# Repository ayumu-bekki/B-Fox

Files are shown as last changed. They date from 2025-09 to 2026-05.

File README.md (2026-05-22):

[English documentation is available here](./README.en.md)

# B-Fox
B-Fox logo

# B-Fox App Store (iOS)
B-Fox Receiver for iOS (https://apps.apple.com/jp/app/b-fox-receiver/id6759365457)

https://apps.apple.com/jp/app/b-fox-receiver/id6759365457

# B-Fox Beacon Control Panel
https://ayumu-bekki.github.io/B-Fox/bfox_beacon/web_client/

## 概要
B-Fox は、Bluetooth Low Energy (BLE) を利用し、Foxハンティングの遊びを再現・実現するためのオープンソースプロジェクトです。
導入・参加の障壁を下げ、「電波の強弱で隠し場所を探す」という無線方向探索のコアな楽しさを手軽に実現することを目指しています。

このプロジェクトを始めるにあたり、既存のFoxハンティング・ARDFに以下のような課題があり手軽でないと感じていました。
- 送信機・受信機のコストが高い
- 運用(ビーコン設置)に免許が必要
- アマチュア無線の帯域を利用するため、商用利用が不可 
- ARDFは競技のため厳格なルールがある

そこで、誰でも免許なしに利用できるBLEを利用して手軽に遊べる無線方向探索の遊びを実現します。

## 運用について
基本遊びだが発展としてARDF競技があるという位置付けを想定し、パークARDFを参考にルールを緩くする方向で運用資料(草案)を作成しました。
[B-Fox 運用・ルール案](./operation/OPERATION.md)

## 送信機・受信機について
[送受信機デバイスドキュメント](./docs/README.md) を参考にしてください。
このプロジェクトには、プログラム一式と、PCB・3Dプリンタで出力できるデータが含まれています。

プロトコルにiBeacon (BLE)を利用しているため、LightBlue (https://punchthrough.com/lightblue/) などをインストールすれば遊ぶことができます。

また、iOS向けに専用受信アプリを用意しています。
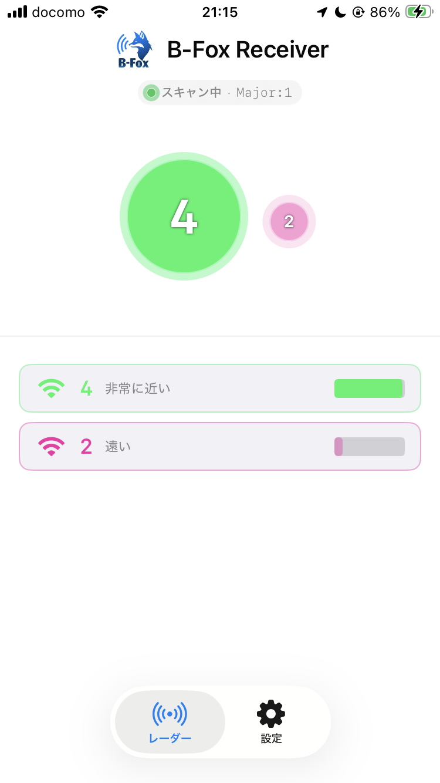
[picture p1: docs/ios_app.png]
B-Fox Receiver for iOS


### QRコードによるビーコン設定
iOS受信アプリでは、QRコードを読み取ってビーコンターゲット（UUID + MajorID）を設定できます。

**QRコードフォーマット:**
```
BFOX:<UUID>:<MajorID>
```

| 要素 | 説明 | 制約 |
|---|---|---|
| `BFOX` | 固定プレフィックス（大文字小文字不問） | 必須 |
| `UUID` | iBeaconのUUID | 標準的なUUID形式 |
| `MajorID` | iBeaconのMajor ID | 整数 0〜65535 |

**例:**
```
BFOX:C65B2C5D-9E53-46EC-8B8E-54D9E2F21188:100
```

### 比較
 
| | ARDF | B-Fox |
| --- | --- | --- |
| 受信機 | 専用もしくはAM受信機が必要 | スマートフォンでも可 |
| 資格 | 受信機設置に第3級アマチュア無線技士以上が必要 | 不要 |
| 無線局免許 | 必要 | 不要 |
| 探知方法 | 音・Sメーター | dBm値 |
| 競技性 | 競技として確立し世界大会がある | 遊び |
| 受信アンテナの自作 | 可能 | 基本的に不可 |
| 利用する周波数 | 3.5MHz / 144MHz | 2.4GHz |
| 空中線出力 | 3.5MHz(3-5W) / 144MHz(0.25-1.5W)程度 | 0.06-8mW |
| 活動範囲 | 数キロメートル | 数百メートル |

## リポジトリ内容説明
送信機・受信機のプログラムと機械設計・運用方法が含まれています。

- bfox_receiver
  - 受信機プログラム一式
- bfox_beacon
  - 送信機プログラム一式
- BFoxReceiverForIOS
  - iOS向け受信用アプリ
- docs
  - 技術資料・PCB・ケース(3Dプリンタ用)
- operation
  - 運用キット

## ライセンス

このプロジェクトは **CERN-OHL-P v2** (CERN Open Hardware Licence Version 2 - Permissive) の下で公開されています。詳細については、[LICENSE](./LICENSE) ファイルを参照してください。

Copyright (c) 2025 Ayumu Bekki

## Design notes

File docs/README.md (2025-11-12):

# B-Foxプロジェクト 技術情報概要

B-Foxは、Bluetooth Low Energy (BLE) を利用し、FOXハンティングの遊びを再現・実現するためのオープンソースプロジェクトです。

---

## 主要コンポーネントとハードウェア

### 送受信機メインモジュール

Seeed Studio XIAO ESP32C6

- BLE による低消費電力での無線通信を実現。
- 外部アンテナ利用可能 技適 (技術基準適合証明) 取得済み
- リポバッテリー対応  携帯利用に適した電源
- 小型フットプリント デバイスの小型化・軽量化

### 受信機インターフェース
キャラクタ液晶表示器を採用
LCDモジュール 16×2行 AQM1602Y-RN-GBW 秋月電子通商取扱([https://akizukidenshi.com/catalog/g/g111916/](https://akizukidenshi.com/catalog/g/g111916/))

---

## ソフトウェアと通信プロトコル

### 開発環境
esp-idf 5.5.1
Espressif IoT Development Framework ([https://github.com/espressif/esp-idf](https://github.com/espressif/esp-idf))

### 通信プロトコル
iBeacon (BLE) プロトコルを利用

GAPを利用し、ビーコン情報を定期的にブロードキャスト
GATTを利用し、送信機の設定変更やバッテリー電圧の取得
スマートフォンアプリ LightBlue ([https://punchthrough.com/lightblue/]https://punchthrough.com/lightblue/)  などで受信可能（この場合、iBeaconではなくGAPによるデバイス名を利用）

---

## ハードウェア製造

送受信機ともにケース・基板 (PCB) のデータを用意しています。
PCBについては、ユニバーサル基板(36x47x1mm)でも作ることが可能です。KiCADの回路図を参考にしてください。
 
PCBWay ([https://www.pcbway.com](https://www.pcbway.com)) などのサービスを利用して基板・ケースの出力が可能です。

- PCB
  - 基板設計情報が含まれています。KiCADで編集が可能です。
    - *_Gerber.zip をそのまま利用できます。(厚さ1mm)
- Case
  - 3Dプリンタで出力できるケースが含まれています。FreeCADで編集が可能です。
    - *.step をそのまま利用できます。

---

##  必要な主要パーツ一覧

リファレンス実装に必要な主要パーツ一覧

### 送信機

| 項目 | 備考 | 個数 |
| --- | ---- | ---- |
| Seeed Studio XIAO ESP32C6 | | 1 |
| リポバッテリー 3000mAh | | 1 |

### 受信機

| 項目 | 備考 | 個数 |
| --- | --- | ---- |
| Seeed Studio XIAO ESP32C6 | | 1 |
| 受信機基板 | | 1 |
| 受信機ケース基盤 | | 1 |
| LCDモジュール AQM1602Y-RN-GBW | | 1 |
| XIAO用ロッドアンテナ | https://akizukidenshi.com/catalog/g/g117582/ | 1 |
| リポバッテリー 500mAh | | 1 |
| 抵抗 | 220kΩ | 2 |
| | 1kΩ | 2 |
| XH端子 | 2P縦型 | 2 |
| XH端子付きケーブル | 2P (ESP32C6のバッテリー接続用) | 1 |
| | 2P横型 | 1 |
| コンデンサ | | |
| スライドスイッチ | 基板実装用 | 1 |
| タクトスイッチ | 基板実装用 | 1 |
| ポリスイッチ | 250mA | 1 |
| 分割ロングピンソケット | 9pin | 1 |
| | 7pin(ロープロファイル) | 2 |
| ネジ | | |
| スペーサー | | |
| 配線用コード | | 適量 |

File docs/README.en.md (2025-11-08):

# B-Fox Project Technical Information Overview

B-Fox is an open-source project that recreates and realizes the fun of amateur radio direction finding (ARDF) using Bluetooth Low Energy (BLE).

---

## Main Components and Hardware

### Transmitter/Receiver Main Module

Seeed Studio XIAO ESP32C6

- Low power wireless communication using BLE
- External antenna capable, Technical Conformity Certification (Giteki) obtained
- LiPo battery compatible, suitable power source for portable use
- Small footprint, enables device miniaturization and weight reduction

### Receiver Interface
Character LCD display adopted
LCD Module 16×2 lines AQM1602Y-RN-GBW Available at Akizuki Denshi Tsusho ([https://akizukidenshi.com/catalog/g/g111916/](https://akizukidenshi.com/catalog/g/g111916/))

---

## Software and Communication Protocol

### Development Environment
esp-idf 5.5.1
Espressif IoT Development Framework ([https://github.com/espressif/esp-idf](https://github.com/espressif/esp-idf))

### Communication Protocol
Uses iBeacon (BLE) protocol

Uses GAP to periodically broadcast beacon information
Uses GATT to change transmitter settings and obtain battery voltage
Can be received with smartphone apps like LightBlue ([https://punchthrough.com/lightblue/](https://punchthrough.com/lightblue/)) (in this case, uses GAP device name instead of iBeacon)

---

## Hardware Manufacturing

Case and PCB data are provided for both transmitters and receivers.
For PCBs, it is also possible to build them on universal boards (36x47x1mm). Please refer to the KiCAD schematics.

Boards and cases can be output using services like PCBWay ([https://www.pcbway.com](https://www.pcbway.com)).

- PCB
  - Contains PCB design information. Editable with KiCAD.
    - *_Gerber.zip can be used as-is. (thickness 1mm)
- Case
  - Cases that can be output with 3D printers are included. Editable with FreeCAD.
    - *.step can be used as-is.

---

## List of Required Main Parts

List of main parts required for reference implementation

### Transmitter

| Item | Notes | Quantity |
| --- | ----- | --- |
| Seeed Studio XIAO ESP32C6 | | 1 |
| LiPo Battery 3000mAh | | 1 |

### Receiver

| Item | Notes | Quantity |
| --- | --- | --- |
| Seeed Studio XIAO ESP32C6  | | 1 |
| Receiver PCB | | 1 |
| Receiver Case Board | | 1 |
| LCD Module AQM1602Y-RN-GBW | | 1 |
| Rod Antenna for XIAO | https://akizukidenshi.com/catalog/g/g117582/ | 1 |
| LiPo Battery 500mAh | | 1 |
| Resistor | 220kΩ | 2 |
| | 1kΩ | 2 |
| XH Connector | 2P Vertical | 2 |
| Cable with XH Connector | 2P (for ESP32C6 battery connection) | 1 |
| | 2P Horizontal | 1 |
| Capacitor | | |
| Slide Switch | For PCB mount | 1 |
| Tactile Switch | For PCB mount | 1 |
| Polyswitch | 250mA | 1 |
| Split Long Pin Socket | 9pin | 1 |
| | 7pin (Low Profile) | 2 |
| Screw | | |
| Spacer | | |
| Wiring Cord | | Appropriate amount |

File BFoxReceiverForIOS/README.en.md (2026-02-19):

# B-Fox Receiver for iOS

An iOS app that visually displays the distance to iBeacons in real time.

> Japanese documentation: [README.md.ja](README.md.ja)

## Overview

B-Fox Receiver scans for iBeacons with a fixed Proximity UUID and shows each detected beacon as a dot whose **size represents signal strength** — the closer the beacon, the larger the dot. A signal-strength bar and optional dBm readout are shown in the list below.

## Features

- Real-time iBeacon ranging via CoreLocation
- Visual dot display: dot size and opacity scale with RSSI
- Floating animation per beacon (unique phase per minor value)
- Beacon list sorted by descending RSSI with proximity label and bar
- Scanning indicator (animated dots) when no beacons are detected
- Major value selector (0–9) to filter beacons by group
- Optional RSSI dBm overlay on dots and list rows
- Location permission denied/restricted state handled with a full-screen prompt
- English / Japanese localization

## Requirements

- iOS 18.6+
- Xcode 16+
- A physical iOS device (iBeacon ranging is not supported in Simulator)

## Getting Started

### 1. Configure your Team ID

Copy the sample config file and fill in your Apple Developer Team ID:

```bash
cp BFoxReceiverForIOS/Config/Local.xcconfig.sample \
   BFoxReceiverForIOS/Config/Local.xcconfig
```

Open `Local.xcconfig` and replace `YOUR_TEAM_ID`:

```
DEVELOPMENT_TEAM = YOUR_TEAM_ID
```

Your Team ID can be found at [developer.apple.com](https://developer.apple.com) under **Membership**, or in **Xcode → Settings → Accounts**.

### 2. Assign the xcconfig in Xcode

1. Open `BFoxReceiverForIOS.xcodeproj` in Xcode.
2. Select the project root in the Project Navigator, then open the **Info** tab.
3. Under **Configurations**, set both **Debug** and **Release** for the `BFoxReceiverForIOS` target to **Base**.

### 3. Build and run

Select a connected device and press **Run** (⌘R).

## Project Structure

```
BFoxReceiverForIOS/
├── Models/
│   ├── BeaconModel.swift       # DetectedBeacon struct
│   └── Constants.swift         # UUID, RSSI thresholds, colors
├── Services/
│   └── BeaconScanner.swift     # CLLocationManager wrapper (@MainActor)
├── Views/
│   ├── RadarView.swift         # Dot-based visual display
│   ├── BeaconListView.swift    # RSSI-sorted list with bar indicator
│   └── SettingsView.swift      # Major selector and display options
├── Config/
│   ├── Base.xcconfig           # Shared build settings (tracked)
│   ├── Local.xcconfig          # Personal settings — Team ID (not tracked)
│   └── Local.xcconfig.sample   # Template for Local.xcconfig
├── ContentView.swift           # Root view with TabView
├── BFoxReceiverForIOSApp.swift # App entry point
└── Localizable.xcstrings       # English / Japanese strings
```

## Beacon Configuration

| Setting | Value |
|---|---|
| Proximity UUID | `C65B2C5D-9E53-46EC-8B8E-54D9E2F21188` |
| Major | Configurable in Settings (0–9) |
| Minor | Used as the beacon identifier and display label |

The UUID is the value defined for B-Fox on the beacon side.

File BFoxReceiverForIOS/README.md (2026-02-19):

# B-Fox Receiver for iOS

iBeacon の距離をリアルタイムにグラフィカル表示する iOS アプリです。

> English documentation: [README.md](README.md)

## 概要

B-Fox Receiver は固定の Proximity UUID を持つ iBeacon をスキャンし、検出したビーコンをドットで表示します。**ドットのサイズが電波強度（RSSI）に比例**し、近いほど大きく表示されます。画面下部のリストには RSSI バーと近接距離ラベルが表示されます。

## 機能

- CoreLocation による iBeacon のリアルタイムレンジング
- ドット表示：サイズと透明度が RSSI に連動
- ビーコンごとに個別位相のフローティングアニメーション
- RSSI 降順のビーコンリスト（近接ラベル・バー付き）
- ビーコン未検出時のスキャン中インジケーター（アニメーションドット）
- Major 値セレクター（0〜9）でビーコングループを絞り込み
- RSSI の dBm 値をドットおよびリスト行に表示するオプション
- 位置情報権限が拒否・制限された場合の全画面プロンプト表示
- 英語 / 日本語ローカライズ対応

## 動作要件

- iOS 18.6 以降
- Xcode 16 以降
- 実機（iBeacon のレンジングはシミュレーターでは動作しません）

## セットアップ

### 1. Team ID を設定

サンプルファイルをコピーして自分の Apple Developer Team ID を設定します。

```bash
cp BFoxReceiverForIOS/Config/Local.xcconfig.sample \
   BFoxReceiverForIOS/Config/Local.xcconfig
```

`Local.xcconfig` を開き、`YOUR_TEAM_ID` を自分の Team ID に書き換えます。

```
DEVELOPMENT_TEAM = YOUR_TEAM_ID
```

Team ID は [developer.apple.com](https://developer.apple.com) の **Membership** ページ、または **Xcode → Settings → Accounts** で確認できます。

### 2. Xcode で xcconfig を割り当て

1. `BFoxReceiverForIOS.xcodeproj` を Xcode で開きます。
2. Project Navigator でプロジェクトルートを選択し、**Info** タブを開きます。
3. **Configurations** セクションで、`BFoxReceiverForIOS` ターゲットの **Debug** と **Release** の両方に **Base** を割り当てます。

### 3. ビルド・実行

接続した実機を選択して **Run**（⌘R）を押します。

## プロジェクト構成

```
BFoxReceiverForIOS/
├── Models/
│   ├── BeaconModel.swift       # DetectedBeacon 構造体
│   └── Constants.swift         # UUID・RSSI 閾値・カラー定義
├── Services/
│   └── BeaconScanner.swift     # CLLocationManager ラッパー（@MainActor）
├── Views/
│   ├── RadarView.swift         # ドットベースのビジュアル表示
│   ├── BeaconListView.swift    # RSSI 降順リスト（バーインジケーター付き）
│   └── SettingsView.swift      # Major セレクターと表示オプション
├── Config/
│   ├── Base.xcconfig           # 共通ビルド設定（git 管理対象）
│   ├── Local.xcconfig          # 個人設定（Team ID など、git 除外）
│   └── Local.xcconfig.sample   # Local.xcconfig のテンプレート
├── ContentView.swift           # TabView を持つルートビュー
├── BFoxReceiverForIOSApp.swift # アプリエントリーポイント
└── Localizable.xcstrings       # 英語 / 日本語文字列
```

## ビーコン設定

| 設定項目 | 値 |
|---|-----|
| Proximity UUID | `C65B2C5D-9E53-46EC-8B8E-54D9E2F21188` |
| Major | 設定画面で選択（0〜9） |
| Minor | ビーコンの識別子・表示ラベルとして使用 |

UUIDはビーコン側でB-Fox用に定義された値となります。

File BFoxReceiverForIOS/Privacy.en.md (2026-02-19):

# Privacy Policy

This privacy policy applies to the B-Fox Receiver app (hereby referred to as "Application") for mobile devices that was created by Ayumu Bekki (hereby referred to as "Service Provider") as a Free service. This service is intended for use "AS IS".

## What information does the Application obtain and how is it used?

The Application does not collect, transmit, or store any personally identifiable information on external servers. Registration is not required to use the Application. However, to enable its core functionality, the Application requires access to certain device capabilities, specifically Bluetooth and Location services, which are processed entirely locally on your device.

## Does the Application collect precise real time location information of the device?

To scan for Bluetooth (iBeacon) signals, the Application must request access to your device's Location and Bluetooth services, as required by the mobile operating system. Please note that this data is processed exclusively on your device. The Service Provider does not collect, transmit, store externally, or share your precise real-time location or Bluetooth scanning data with any third parties.

## Do third parties see and/or have access to information obtained by the Application?

Since the Application does not collect any information, no data is shared with third parties.

## What are my opt-out rights?

You can stop all collection of information by the Application easily by uninstalling it. You may use the standard uninstall processes as may be available as part of your mobile device or via the mobile application marketplace or network.

## Children

The Application is not used to knowingly solicit data from or market to children under the age of 13.

The Service Provider does not knowingly collect personally identifiable information from children. The Service Provider encourages all children to never submit any personally identifiable information through the Application and/or Services. The Service Provider encourage parents and legal guardians to monitor their children's Internet usage and to help enforce this Policy by instructing their children never to provide personally identifiable information through the Application and/or Services without their permission. If you have reason to believe that a child has provided personally identifiable information to the Service Provider through the Application and/or Services, please contact the Service Provider (ayumu@bekki.jp) so that they will be able to take the necessary actions. You must also be at least 16 years of age to consent to the processing of your personally identifiable information in your country (in some countries we may allow your parent or guardian to do so on your behalf).

## Security

The Service Provider is concerned about safeguarding the confidentiality of your information. However, since the Application does not collect any information, there is no risk of your data being accessed by unauthorized individuals.

## Changes

This Privacy Policy may be updated from time to time for any reason. The Service Provider will notify you of any changes to their Privacy Policy by updating this page with the new Privacy Policy. You are advised to consult this Privacy Policy regularly for any changes, as continued use is deemed approval of all changes.

This privacy policy is effective as of 2026-02-19

## Your Consent

By using the Application, you are consenting to the processing of your information as set forth in this Privacy Policy now and as amended by the Service Provider.

## Contact Us

If you have any questions regarding privacy while using the Application, or have questions about the practices, please contact the Service Provider via email at ayumu@bekki.jp.

---

*This privacy policy page was generated by [App Privacy Policy Generator](https://app-privacy-policy-generator.nisrulz.com/) and modified by the Service Provider.*

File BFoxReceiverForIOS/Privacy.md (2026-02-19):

# プライバシーポリシー

本プライバシーポリシーは、Ayumu Bekki（以下「サービス提供者」）が無料で提供するモバイルデバイス向けアプリ「B-Fox Receiver」（以下「本アプリ」）に適用されます。本サービスは「現状有姿（AS IS）」で提供されるものです。

## 本アプリが取得する情報およびその使用方法

本アプリは、外部サーバーへの個人を特定できる情報の収集、送信、保存は一切行いません。本アプリを使用するためのユーザー登録は不要です。ただし、アプリの主要機能を実現するため、デバイスの特定の機能（具体的にはBluetoothおよび位置情報サービス）へのアクセスを必要としますが、これらの処理はお客様のデバイス内でローカルに完結して行われます。

## 本アプリはデバイスの正確なリアルタイム位置情報を収集しますか？

Bluetooth（iBeacon）信号をスキャンするため、モバイルOSの要件に従い、本アプリはデバイスの位置情報サービスおよびBluetoothへのアクセスを要求する必要があります。なお、このデータはお客様のデバイス上でのみ処理されます。サービス提供者が、お客様の正確なリアルタイムの位置情報やBluetoothスキャンデータを収集、送信、外部に保存、または第三者と共有することは一切ありません。

## 第三者は本アプリが取得した情報を閲覧またはアクセスできますか？

本アプリはいかなる情報も収集・送信しないため、第三者とデータが共有されることはありません。

## オプトアウトの権利について

お客様は、本アプリをアンインストールすることで、本アプリによる情報の利用（権限へのアクセス）を簡単に停止できます。デバイス、またはモバイルアプリのマーケットプレイスやネットワークで提供されている標準的なアンインストール手順をご利用いただけます。

## 児童のプライバシー

本アプリは、13歳未満の児童から意図的にデータを収集したり、マーケティングを行ったりすることはありません。

サービス提供者は、児童から意図的に個人を特定できる情報を収集することはありません。サービス提供者は、すべての児童に対し、本アプリおよびサービスを通じて個人を特定できる情報を送信しないよう推奨します。サービス提供者は、保護者および法定代理人に対し、児童のインターネット使用状況を監視し、児童が許可なく本アプリおよびサービスを通じて個人を特定できる情報を提供しないよう指導することで、本ポリシーの遵守を支援することを推奨します。児童が本アプリを通じてサービス提供者に個人を特定できる情報を提供したと疑われる場合は、必要な措置を講じることができるよう、サービス提供者（ayumu@bekki.jp）までご連絡ください。また、お客様の国において個人情報の処理に同意するには、16歳以上である必要があります（一部の国では、保護者または法定代理人による代理同意を認める場合があります）。

## セキュリティ

サービス提供者は、お客様の情報の機密性を保護することに努めています。しかしながら、本アプリはそもそもユーザーの情報を外部に収集・保存していないため、不正な第三者によってお客様のデータにアクセスされるリスクはありません。

## 変更について

本プライバシーポリシーは、理由の如何を問わず随時更新される場合があります。サービス提供者は、このページを新しいプライバシーポリシーに更新することで、変更をお客様に通知します。本アプリの継続的な使用はすべての変更への同意とみなされるため、本プライバシーポリシーを定期的に確認することをお勧めします。

本プライバシーポリシーは2026年2月19日より有効です。

## お客様の同意

本アプリを使用することにより、お客様は、本プライバシーポリシー（サービス提供者による改定を含みます）に定められた情報の取り扱いに同意したものとみなされます。

## お問い合わせ

本アプリのプライバシーに関するご質問、または当方の運用に関するご質問がある場合は、サービス提供者宛てにメール（ayumu@bekki.jp）でご連絡ください。

---

*本プライバシーポリシーは [App Privacy Policy Generator](https://app-privacy-policy-generator.nisrulz.com/) によって生成され、サービス提供者によって修正・翻訳されたものです。*

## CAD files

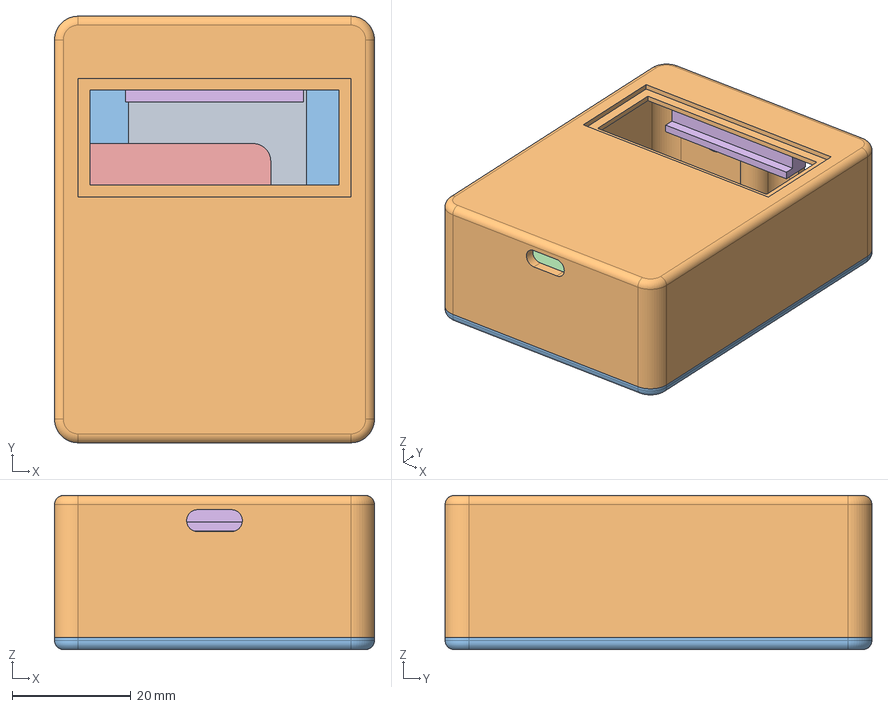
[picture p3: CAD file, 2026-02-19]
docs/Case/bfox_Receiver_Case.FCStd
54.0 x 72.0 x 26.0 mm
Battery250
Lid
PCB
PCBCover
LCDFix

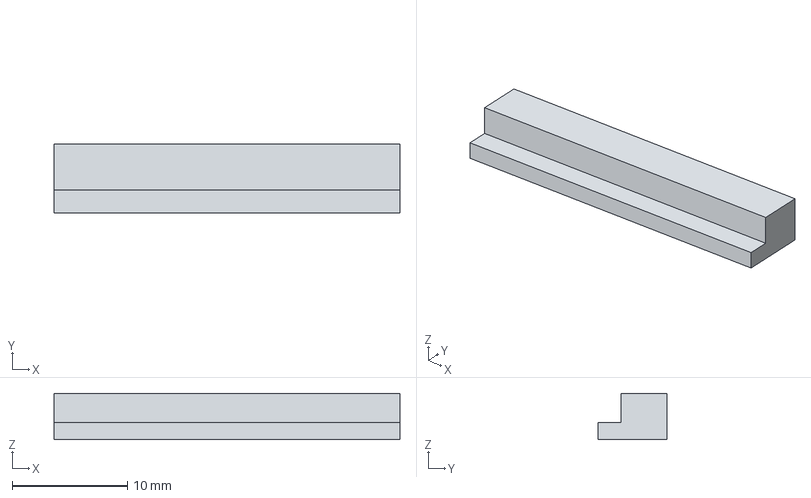
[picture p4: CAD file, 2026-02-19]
docs/Case/bfox_receiver_case-LCDFix.step
30.0 x 6.00 x 4.00 mm

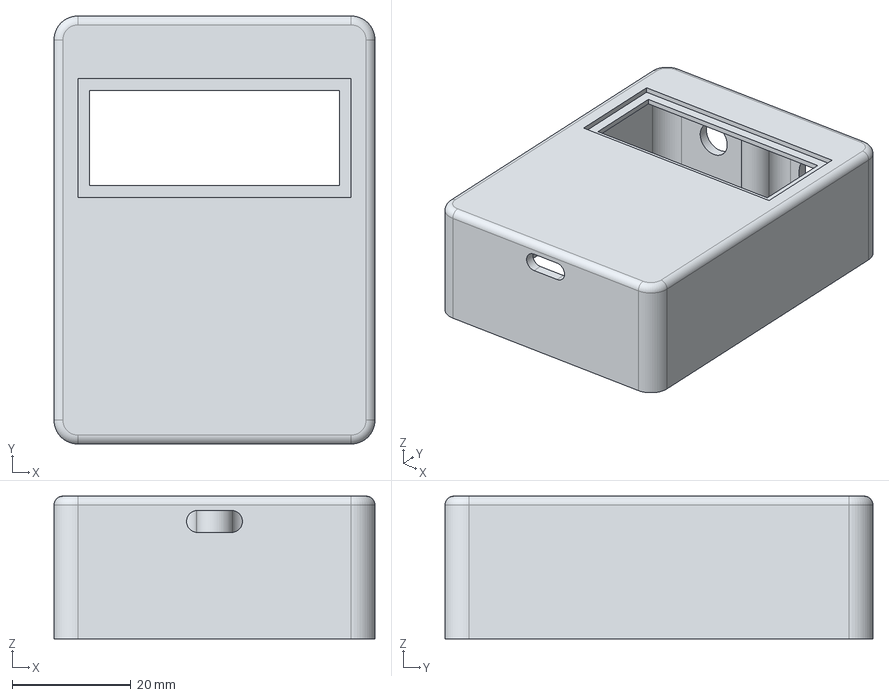
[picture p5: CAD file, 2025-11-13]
docs/Case/bfox_receiver_case-Body.step
54.0 x 72.0 x 24.0 mm

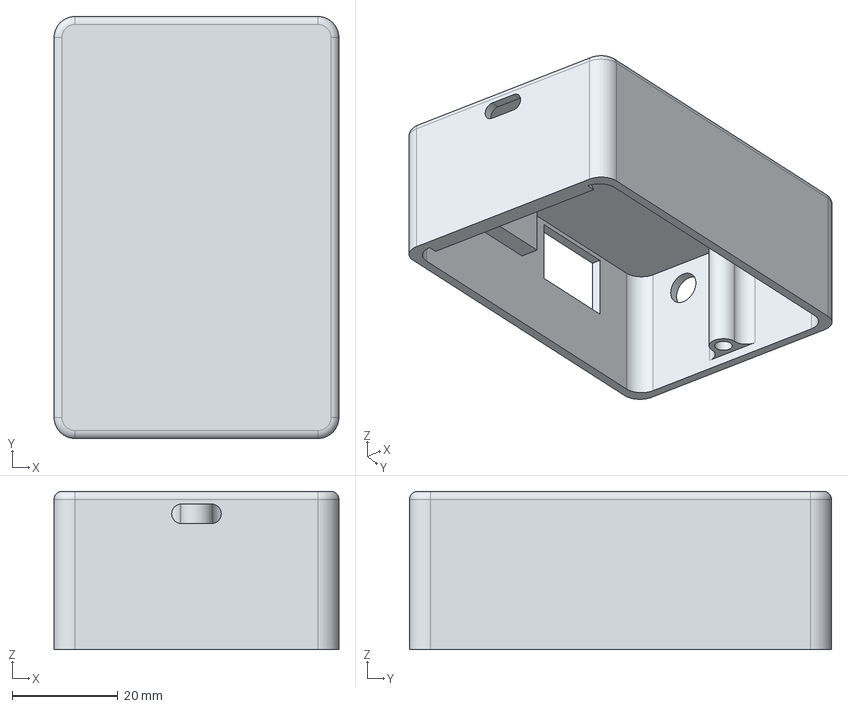
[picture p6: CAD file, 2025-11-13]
docs/Case/bfox_beacon_case-Body.step
54.0 x 80.0 x 30.0 mm

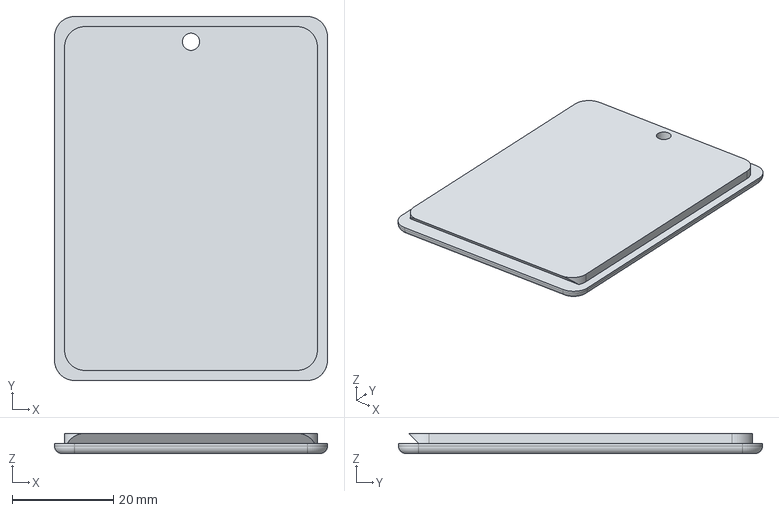
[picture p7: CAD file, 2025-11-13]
docs/Case/bfox_receiver_case-Lid.step
54.0 x 72.0 x 4.00 mm

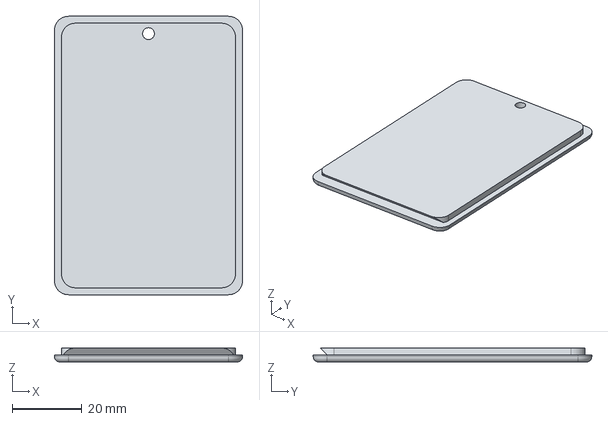
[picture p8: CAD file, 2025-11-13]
docs/Case/bfox_beacon_case-Lid.step
54.0 x 80.0 x 4.00 mm

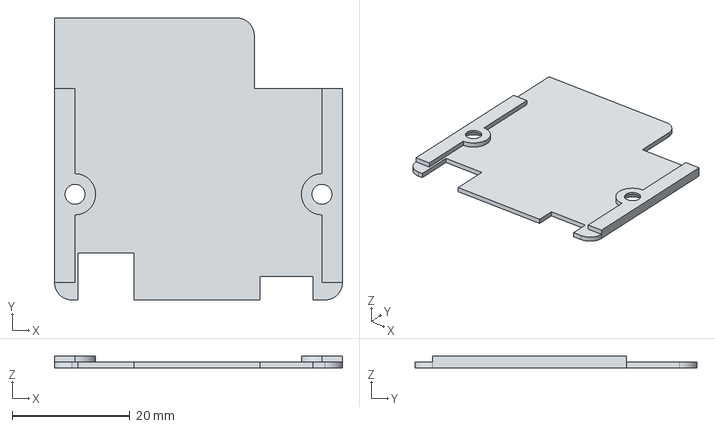
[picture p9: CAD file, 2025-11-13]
docs/Case/bfox_receiver_case-PCBCover.step
49.0 x 48.0 x 2.00 mm

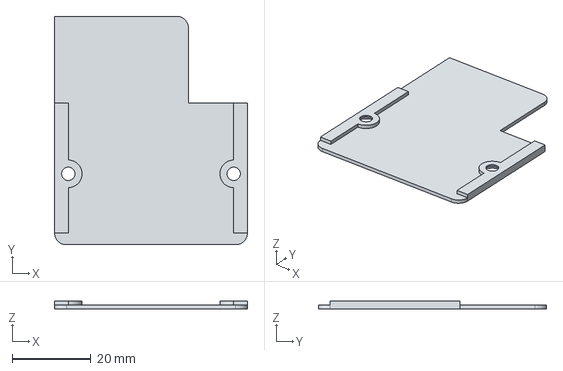
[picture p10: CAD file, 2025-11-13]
docs/Case/bfox_beacon_case-PCBCover.step
49.0 x 58.0 x 2.00 mm

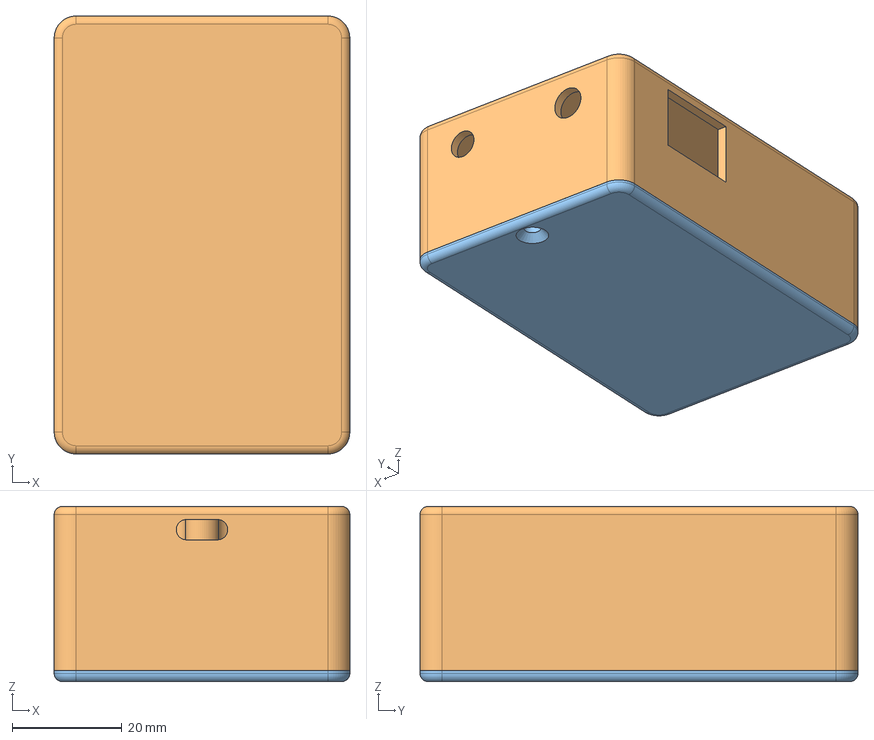
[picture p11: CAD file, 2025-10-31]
docs/Case/bfox_Beacon_Case.FCStd
54.0 x 80.0 x 32.0 mm
Battery3000
Lid
PCB
PCBCover

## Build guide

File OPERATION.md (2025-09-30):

# BleRDF 運用・ルール案

BleRDFは従来のARDF（アマチュア無線方向探知）を、Bluetooth iBeaconを利用し「宝探し遊び」としてアレンジした、手軽に楽しめるアウトドアゲームです。

## 1. 必要な機材

| 役割 | 機材 | 備考 |
| ---- | ---- | ---- |
| プレイヤー | 1. 受信機 | 専用受信機もしくはBLE探索アプリを入れたスマートフォンを使います。 | 
| | 2. 記録カード | 発見した証（スタンプやシール）を記録するためのもの。QRコードで記録する場合は不要 | 
| 主催者 | 1\. ビーコン | 少なくとも3〜5個程度。電源が入っていること。 | 
| | 2. 記録用の道具 | スタンプ/シール、または記録用のQRコード設置物。 | 
| | 3. エリアマップ | 捜索範囲がわかる簡単な地図。スタート位置と範囲を記載しておく |  

## 2. 準備と設置（主催者向け）

### A. エリア選定とルール設定

1. 安全なエリアの選定
  - 公園、敷地内の森、広場など、安全に移動できる範囲を設定します。
  -  危険な場所（崖、許可をとっていない私有地、水場、交通量の多い道路付近）は避けます。  
2. 捜索範囲の指定
  - エリアマップに明確な境界線を引き、プレイヤーに伝達します。  
3. クリア条件の決定
  -  必要に応じて「全てのビーコンを見つける」「3つ以上のビーコンを見つける」など、目標となる発見数を定めます。

### B. ビーコンと記録ポイントの設置

- 簡単な隠し場所
  - ビーコン本体は、プレイヤーが簡単に手で触れられる範囲に設置します。  
- 記録ポイントの設置
  - ビーコンのすぐ近くに、記録カードに押すスタンプ、シール、またはデジタル記録用のQRコードを設置します。  
  - 記録ポイントには、発見したビーコンと一致する**ユニークなマーク**（例：アルファベットや動物の絵）を明記しておきます。  
- 設置したビーコンのテスト実施
  - 事前に会場でビーコンの信号強度（RSSI）をテストし、おおよそどの程度の距離で「近づいた」と判断できるかを確認します。  
  - バッテリー駆動の場合は、電圧が適切か、競技時間中も安定して信号を発信できるかを確認します。

## 3. 遊び方

### 1. スタート

- 主催者から必要に応じて記録カードを受け取ります。
- 受信機、もしくはスマートフォンで LightBlue を起動し、計測を開始します。

### 2. 方向探知

- 信号強度（RSSI）の利用
  - 最も強い信号（最も数字の絶対値が小さいもの）をターゲットにします。
- 方向の推測
  - 信号が強くなる方向（RSSI値が小さくなる方向）を推測しながら進みます。
  - BLEは2.4GHzの電波であり、建物や地形によって信号が反射したり、遮られたりします。
信号の変化をよく観察しながら、慎重に方向を推測することが重要です。
- シールド技術
  - BLEは電波が弱く、身体や障害物で容易に遮蔽されます。受信機とビーコンの間に自分の身体を入れることで信号を遮り、信号が弱くなる方向の逆がビーコンのおおよその方向だと判断するテクニックが有効です

### 3. 発見と記録

- 信号強度が一定の基準（-50dBm以下）になったら、物理的に周囲を捜索します。 
  - この基準値はあくまで目安です。受信機や周辺環境によって変動するため、現場のテスト結果を優先してください。
- 隠されているビーコンを見つけたら、その場にあるスタンプ、またはシール・QRコードを使って証拠を残します

### 4. ゴール

- 設定されたクリア条件（例：3つのビーコンの記録を全て集める）を達成したら、速やかにスタート地点に戻りゴールします
- 主催者による記録カードのチェックを受けます。

## 4. ルール設定と楽しみ方

### 純粋な宝探しとして楽しむ場合

- 時間内に全てのビーコンを見つけることを目標とします
- 順位をつけず、純粋に「見つけられたこと」を楽しみます。1つでも見つけることができればOKとし、初心者でも楽しめるようにします

### 競技として楽しむ場合

- 設定された数のビーコンを最も短時間で発見し、かつ記録に不備がないプレイヤーを勝者とします
- 誤った証拠を記録していた場合、または危険行為があった場合は失格とします。

## 5. 安全に関する注意事項

- 自己責任の原則
  - 競技中の怪我や事故は、参加者自身の責任となります。保険加入や体調管理を徹底してください
- 周辺への配慮
  - 一般の利用者がいる場所では、走らず、他の利用者や車両の通行を妨げないように注意して移動してください
  - 植え込みや樹木など、自然物を傷つけないように配慮してください
- 緊急連絡先の周知
  - 緊急時にすぐに連絡できる体制を整えてください

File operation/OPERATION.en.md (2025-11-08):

# B-Fox Operation & Rules Draft

B-Fox is an easy-to-enjoy outdoor game, an adaptation of traditional ARDF (Amateur Radio Direction Finding), using Bluetooth iBeacons for a "treasure hunt" style experience.

## 1. Required Equipment

| Role | Equipment | Notes |
| --- | --- | --- |
| Player | 1. Receiver | Use a dedicated receiver or a smartphone with a BLE scanning app. |
| | 2. Record Card | For recording proof of discovery (stamps or stickers). Not required if using QR codes for recording. |
| Organizer | 1. Beacons | At least 3-5. Ensure they are powered on. |
| | 2. Recording Tools | Stamps/stickers, or QR code placements for recording. |
| | 3. Area Map | A simple map showing the search area. Mark the start position and boundaries. |

## 2. Preparation and Setup (for Organizers)

### A. Area Selection and Rule Setting

1. **Select a Safe Area**
   - Choose a safe area for movement, such as a park, a private forest, or a large open field.
   - Avoid dangerous places (cliffs, unauthorized private property, bodies of water, areas near heavy traffic).
2. **Define the Search Area**
   - Draw clear boundaries on the area map and communicate them to the players.
3. **Determine the Winning Conditions**
   - If necessary, set a target number of discoveries, such as "find all beacons" or "find 3 or more beacons."

### B. Beacon and Recording Point Placement

- **Simple Hiding Spots**
  - Place the beacons where players can easily reach them by hand.
- **Set up Recording Points**
  - Near each beacon, place a stamp, sticker, or a QR code for digital recording.
  - Clearly mark each recording point with a **unique identifier** (e.g., an alphabet letter or an animal picture) that corresponds to the discovered beacon.
- **Test Placed Beacons**
  - Test the signal strength (RSSI) of the beacons at the venue beforehand to determine the approximate distance at which a player is considered "close."
  - For battery-powered beacons, check if the voltage is adequate and if they can broadcast a stable signal for the duration of the event.

## 3. How to Play

### 1. Start

- Receive a record card from the organizer if needed.
- Start your receiver or launch a BLE scanner app like LightBlue on your smartphone and begin scanning.

### 2. Direction Finding

- **Using Signal Strength (RSSI)**
  - Target the strongest signal (the one with the smallest absolute number).
- **Estimating Direction**
  - Proceed in the direction where the signal gets stronger (the RSSI value decreases).
  - BLE uses a 2.4GHz radio frequency, and signals can be reflected or blocked by buildings and terrain. It's important to carefully observe signal changes to estimate the direction.
- **Shielding Technique**
  - BLE signals are weak and easily blocked by the body or obstacles. A useful technique is to place your body between the receiver and the suspected beacon location. If the signal weakens, the beacon is likely in the opposite direction.

### 3. Discovery and Recording

- **Physical Search**
  - When the signal strength reaches a certain threshold (e.g., below -50dBm), start a physical search of the immediate surroundings.
  - This threshold is just a guideline. It can vary depending on the receiver and the environment, so prioritize the results of on-site testing.
- **Record Your Find**
  - Once you find the hidden beacon, use the provided stamp, sticker, or QR code to record your discovery.

### 4. Goal

- **Finish**
  - Once you meet the set winning conditions (e.g., collecting records for 3 beacons), return to the starting point promptly to finish.
- **Verification**
  - Have your record card checked by the organizer.

## 4. Rule Setting and Enjoyment

### For a Pure Treasure Hunt

- The goal is to find all the beacons within the time limit.
- Enjoy the act of finding itself without ranking. Finding even one beacon is a success, making it enjoyable for beginners.

### For a Competition

- The winner is the player who finds the set number of beacons in the shortest time with no recording errors.
- Players may be disqualified for recording incorrect proof or for dangerous behavior.

## 5. Safety Precautions

- **Principle of Self-Responsibility**
  - Participants are responsible for their own injuries or accidents during the event. Please ensure you have insurance and are in good health.
- **Consideration for Others**
  - In areas with the general public, do not run and be careful not to obstruct other people or vehicles.
  - Be mindful not to damage natural features like bushes and trees.
- **Emergency Contact Information**
  - Have a system in place for immediate contact in case of an emergency.

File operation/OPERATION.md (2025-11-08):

# B-Fox 運用・ルール案

[English documentation is available here](./OPERATION.en.md)

B-Foxは従来のARDF（アマチュア無線方向探知）を、Bluetooth iBeaconを利用し「宝探し遊び」としてアレンジした、手軽に楽しめるアウトドアゲームです。

## 1. 必要な機材

| 役割 | 機材 | 備考 |
| --- | --- | --- |
| プレイヤー | 1. 受信機 | 専用受信機もしくはBLE探索アプリを入れたスマートフォンを使います。 |
| | 2. 記録カード | 発見した証（スタンプやシール）を記録するためのもの。QRコードで記録する場合は不要 |
| 主催者 | 1\. ビーコン | 少なくとも3〜5個程度。電源が入っていること。 |
| | 2. 記録用の道具 | スタンプ/シール、または記録用のQRコード設置物。 |
| | 3. エリアマップ | 捜索範囲がわかる簡単な地図。スタート位置と範囲を記載しておく |

## 2. 準備と設置（主催者向け）

### A. エリア選定とルール設定

1. 安全なエリアの選定
  - 公園、敷地内の森、広場など、安全に移動できる範囲を設定します。
  -  危険な場所（崖、許可をとっていない私有地、水場、交通量の多い道路付近）は避けます。  
2. 捜索範囲の指定
  - エリアマップに明確な境界線を引き、プレイヤーに伝達します。  
3. クリア条件の決定
  -  必要に応じて「全てのビーコンを見つける」「3つ以上のビーコンを見つける」など、目標となる発見数を定めます。

### B. ビーコンと記録ポイントの設置

- 簡単な隠し場所
  - ビーコン本体は、プレイヤーが簡単に手で触れられる範囲に設置します。  
- 記録ポイントの設置
  - ビーコンのすぐ近くに、記録カードに押すスタンプ、シール、またはデジタル記録用のQRコードを設置します。  
  - 記録ポイントには、発見したビーコンと一致する**ユニークなマーク**（例：アルファベットや動物の絵）を明記しておきます。  
- 設置したビーコンのテスト実施
  - 事前に会場でビーコンの信号強度（RSSI）をテストし、おおよそどの程度の距離で「近づいた」と判断できるかを確認します。  
  - バッテリー駆動の場合は、電圧が適切か、競技時間中も安定して信号を発信できるかを確認します。

## 3. 遊び方

### 1. スタート

- 主催者から必要に応じて記録カードを受け取ります。
- 受信機、もしくはスマートフォンで LightBlue を起動し、計測を開始します。

### 2. 方向探知

- 信号強度（RSSI）の利用
  - 最も強い信号（最も数字の絶対値が小さいもの）をターゲットにします。
- 方向の推測
  - 信号が強くなる方向（RSSI値が小さくなる方向）を推測しながら進みます。
  - BLEは2.4GHzの電波であり、建物や地形によって信号が反射したり、遮られたりします。
信号の変化をよく観察しながら、慎重に方向を推測することが重要です。
- シールド技術
  - BLEは電波が弱く、身体や障害物で容易に遮蔽されます。受信機とビーコンの間に自分の身体を入れることで信号を遮り、信号が弱くなる方向の逆がビーコンのおおよその方向だと判断するテクニックが有効です

### 3. 発見と記録

- 信号強度が一定の基準（-50dBm以下）になったら、物理的に周囲を捜索します。 
  - この基準値はあくまで目安です。受信機や周辺環境によって変動するため、現場のテスト結果を優先してください。
- 隠されているビーコンを見つけたら、その場にあるスタンプ、またはシール・QRコードを使って証拠を残します

### 4. ゴール

- 設定されたクリア条件（例：3つのビーコンの記録を全て集める）を達成したら、速やかにスタート地点に戻りゴールします
- 主催者による記録カードのチェックを受けます。

## 4. ルール設定と楽しみ方

### 純粋な宝探しとして楽しむ場合

- 時間内に全てのビーコンを見つけることを目標とします
- 順位をつけず、純粋に「見つけられたこと」を楽しみます。1つでも見つけることができればOKとし、初心者でも楽しめるようにします

### 競技として楽しむ場合

- 設定された数のビーコンを最も短時間で発見し、かつ記録に不備がないプレイヤーを勝者とします
- 誤った証拠を記録していた場合、または危険行為があった場合は失格とします。

## 5. 安全に関する注意事項

- 自己責任の原則
  - 競技中の怪我や事故は、参加者自身の責任となります。保険加入や体調管理を徹底してください
- 周辺への配慮
  - 一般の利用者がいる場所では、走らず、他の利用者や車両の通行を妨げないように注意して移動してください
  - 植え込みや樹木など、自然物を傷つけないように配慮してください
- 緊急連絡先の周知
  - 緊急時にすぐに連絡できる体制を整えてください

## 6.運営で考慮する点

### ビーコンを不審物と誤解させないための具体的な対策
印字入り防水ステッカーをビーコンに貼ってください。
特に危険物でない遊び道具であることを示すようにすることが重要です。
サンプルをdocs以下に配置しますので参考にしてください。(ToDo)

電波発信中
これは電波を出す遊具です。危険物ではありません。
手を触れずにそっとしておいていただけますと幸いです。

主催：
日時：
連絡先：
メモ欄

QRコードの活用： 上記情報に加え、QRコードを貼り付け、読み取るとスポーツのルールや連絡先が書かれた簡単なウェブサイトに飛ぶようにしておくと非常に親切です。

### 掲示文例
本日探索イベント開催中／器材設置あり

【探索イベント実施のお知らせ】
本日、このエリアで電波を利用した探索イベントを行っております。 
ルール上、コース内に目印となる箱を複数設置しております。
ご利用の皆様にはご迷惑をおかけしますが、ご理解ご協力のほど、よろしくお願いいたします。

### 公園管理者に許可を取るための説明文テンプレ
- B-Foxは"オリエンテーリング"やGPSを使った宝探しゲームである"ジオキャッシング"に似た、知的な探索型の遊びです
- 活動日時、参加人数、活動エリアの地図（どこに装置を設置する可能性があるか）を提出します
- 指定されたポイントに電波を出す装置を設置します。これは環境に悪影響を与えない安全な装置です。
  - 器具に説明ラベルを張り、万が一参加者以外の方が見つけてしまった場合の対策も行っています
  - スタッフが60分毎に巡回します。
- 監視・説明員を配置します。スタッフを1名以上配置し、周囲に気を配り声をかけられた際にすぐ説明できるようにしておきます。
- 入り口に説明資料を掲示します。

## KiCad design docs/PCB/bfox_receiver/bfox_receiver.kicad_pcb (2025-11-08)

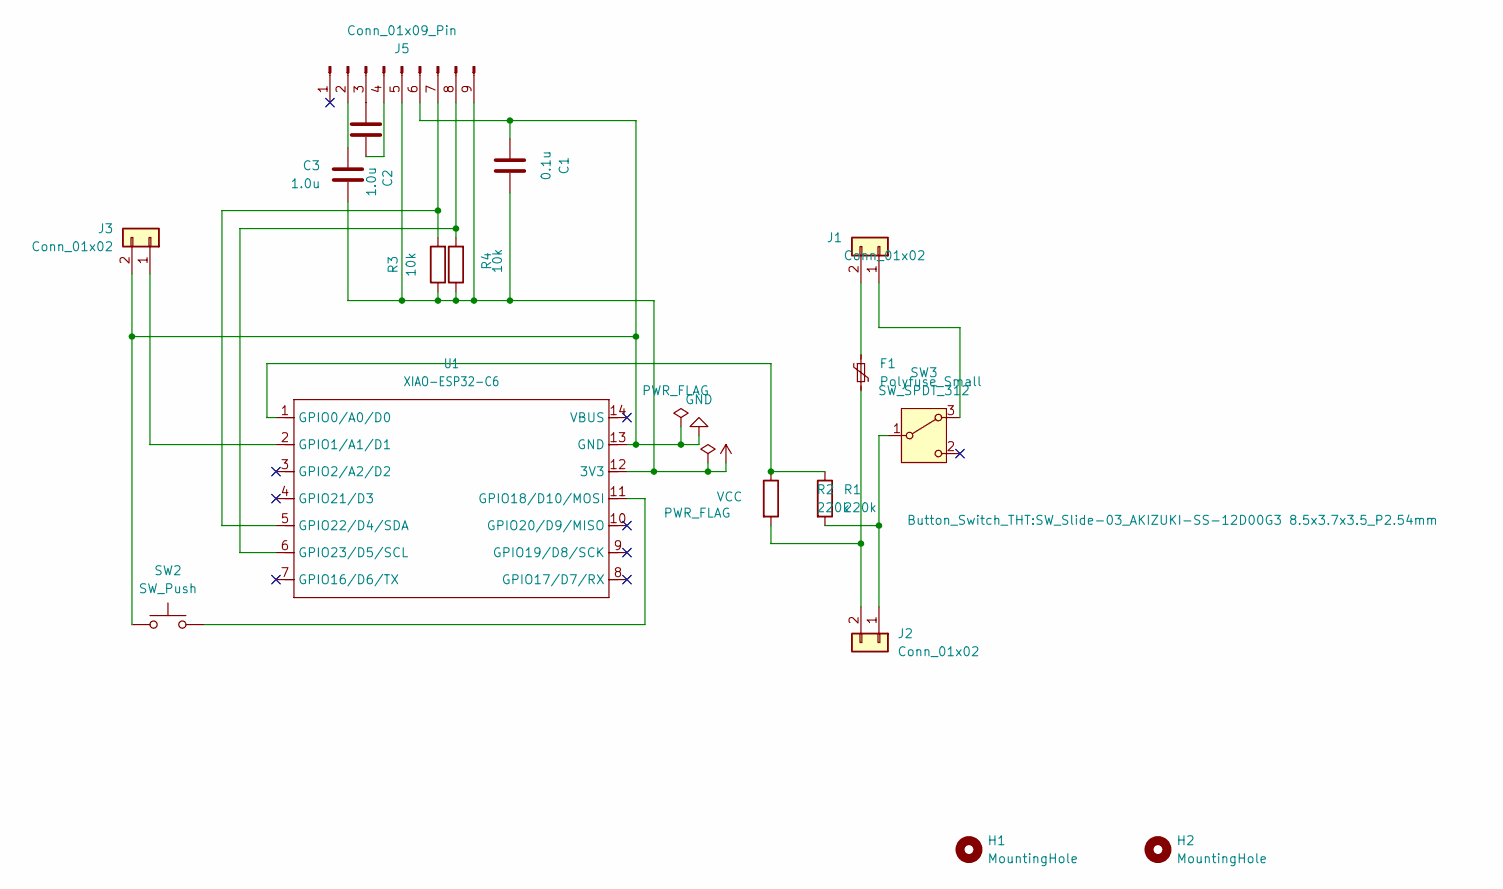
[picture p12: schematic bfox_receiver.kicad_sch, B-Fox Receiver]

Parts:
C1: 0.1u; C_Disc_D3.0mm_W1.6mm_P2.50mm
C2, C3: 1.0u; C_Disc_D3.0mm_W1.6mm_P2.50mm
F1: Polyfuse_Small; C_Disc_D4.3mm_W1.9mm_P5.00mm
H1, H2: MountingHole; MountingHole_3.2mm_M3
J1: Conn_01x02; JST_XH_S2B-XH-A-1_1x02_P2.50mm_Horizontal
J2, J3: Conn_01x02; JST_XH_B2B-XH-A_1x02_P2.50mm_Vertical
J5: Conn_01x09_Pin; PinSocket_1x09_P2.54mm_Vertical
R1, R2: 220k; R_Axial_DIN0204_L3.6mm_D1.6mm_P7.62mm_Horizontal
R3, R4: 10k; R_Axial_DIN0204_L3.6mm_D1.6mm_P7.62mm_Horizontal
SW2: SW_Push; SW_PUSH_6mm_H5mm
SW3: SW_SPDT_312; SW_Slide-03_AKIZUKI-SS-12D00G3 8.5x3.7x3.5_P2.54mm
U1: XIAO-ESP32-C6; XIAO-ESP32C6-DIP

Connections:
GND: C1.2, J3.2, J5.6, SW2.1, U1.13 (GND)
unnamed: J1.1, SW3.3 (A)
unnamed: F1.1, J1.2
unnamed: J2.1, R1.2, SW3.1 (B)
unnamed: F1.2, J2.2, R2.2
unnamed: J3.1, U1.2 (GPIO1/A1/D1)
unnamed: C3.2, J5.2
unnamed: C2.1, J5.3
unnamed: C2.2, J5.4
unnamed: J5.7, R3.2, U1.5 (GPIO22/D4/SDA)
unnamed: J5.8, R4.2, U1.6 (GPIO23/D5/SCL)
unnamed: R1.1, R2.1, U1.1 (GPIO0/A0/D0)
unnamed: SW2.2, U1.11 (GPIO18/D10/MOSI)
VCC: C1.1, C3.1, J5.5, J5.9, R3.1, R4.1, U1.12 (3V3)

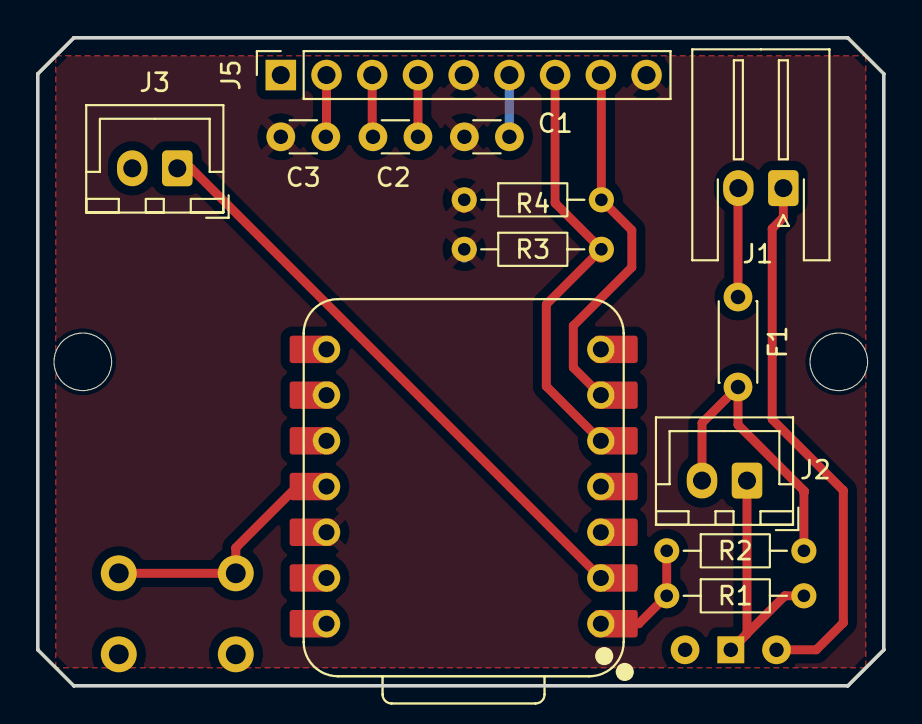
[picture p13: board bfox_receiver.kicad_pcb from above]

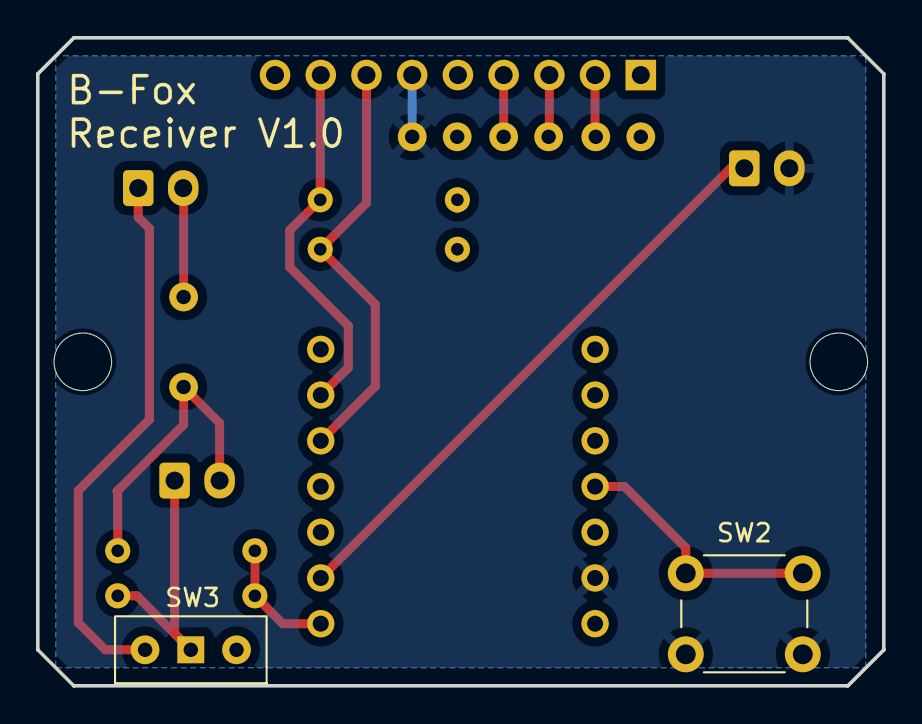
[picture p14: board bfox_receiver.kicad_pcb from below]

Board: 2 copper layers, 47.0 x 36.0 mm, 17 parts (2 on the bottom side), 14 nets.

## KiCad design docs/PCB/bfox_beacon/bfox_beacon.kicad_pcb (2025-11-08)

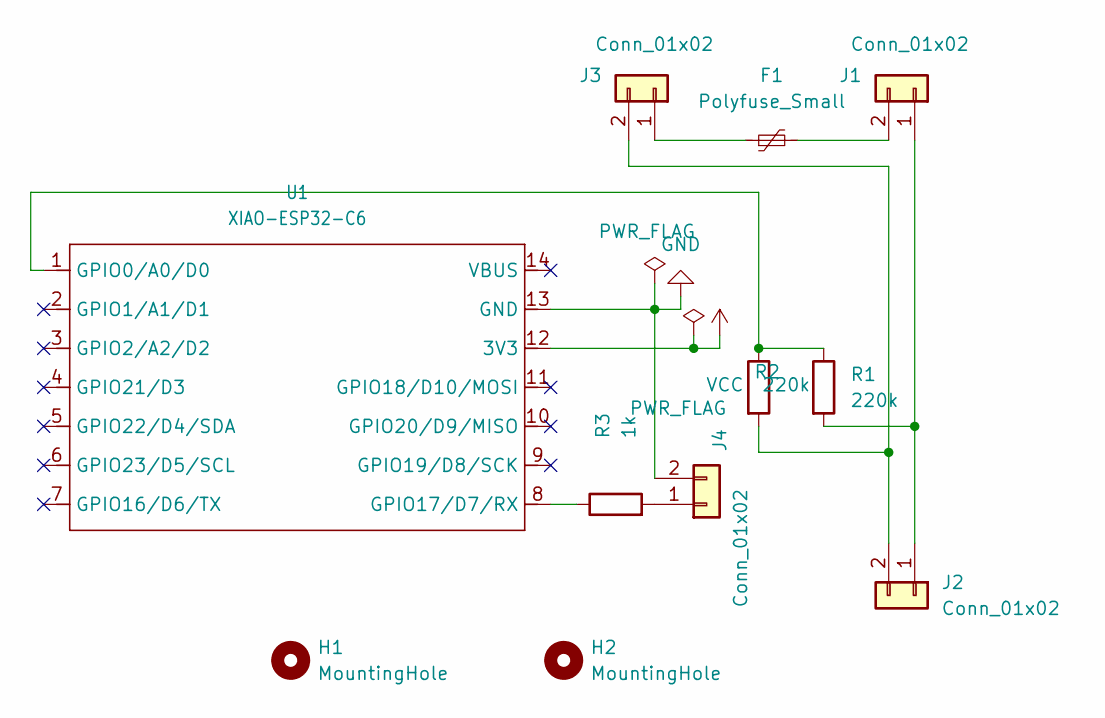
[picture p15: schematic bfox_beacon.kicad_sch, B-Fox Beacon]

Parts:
F1: Polyfuse_Small; C_Disc_D4.3mm_W1.9mm_P5.00mm
H1, H2: MountingHole; MountingHole_3.2mm_M3
J1: Conn_01x02; JST_XH_S2B-XH-A-1_1x02_P2.50mm_Horizontal
J2, J3, J4: Conn_01x02; JST_XH_B2B-XH-A_1x02_P2.50mm_Vertical
R1, R2: 220k; R_Axial_DIN0204_L3.6mm_D1.6mm_P7.62mm_Horizontal
R3: 1k; R_Axial_DIN0207_L6.3mm_D2.5mm_P7.62mm_Horizontal
U1: XIAO-ESP32-C6; XIAO-ESP32C6-DIP

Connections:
GND: J4.2, U1.13 (GND)
unnamed: J1.1, J2.1, R1.2
unnamed: F1.2, J1.2
unnamed: J2.2, J3.2, R2.2
unnamed: F1.1, J3.1
unnamed: J4.1, R3.2
unnamed: R1.1, R2.1, U1.1 (GPIO0/A0/D0)
unnamed: R3.1, U1.8 (GPIO17/D7/RX)
VCC: U1.12 (3V3)

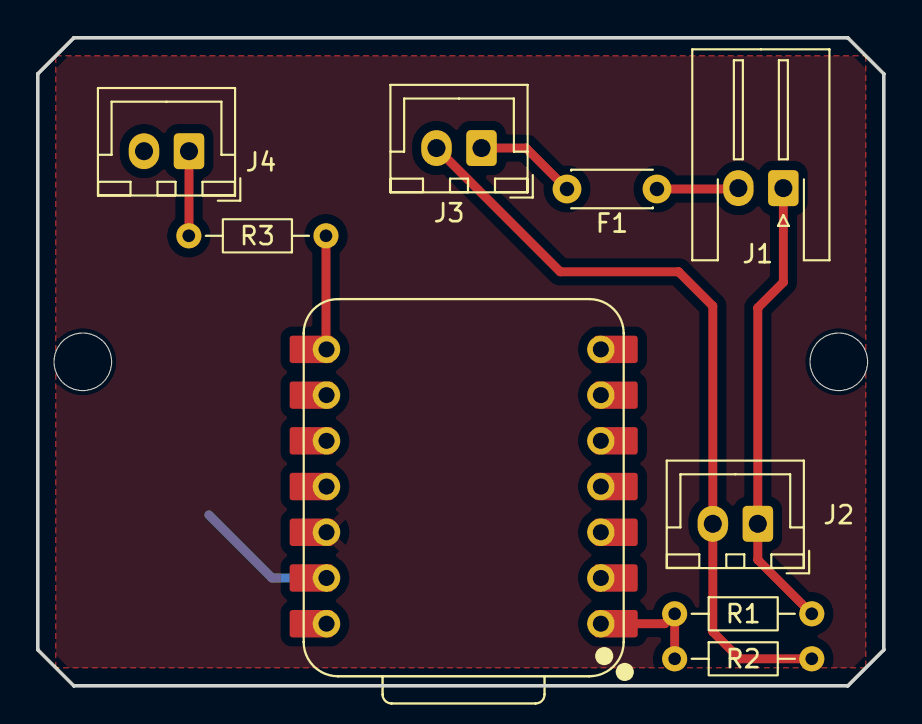
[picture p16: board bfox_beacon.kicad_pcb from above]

Board: 2 copper layers, 47.0 x 36.0 mm, 11 parts (0 on the bottom side), 8 nets.

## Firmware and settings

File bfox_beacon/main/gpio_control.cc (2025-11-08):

// ESP32 B-Fox Beacon
// (C)2025 bekki.jp

#include "gpio_control.h"

#include <driver/gpio.h>
#include <esp_adc/adc_cali.h>
#include <esp_adc/adc_cali_scheme.h>
#include <esp_adc/adc_oneshot.h>

#include "logger.h"

namespace bfox_beacon_system {
namespace gpio {

/// Init GPIO ISR Service
void InitGpioIsrService() { gpio_install_isr_service(0); }

/// Reset GPIO
void Reset(const gpio_num_t gpio_number) { gpio_reset_pin(gpio_number); }

/// Init GPIO (Output)
void InitOutput(const gpio_num_t gpio_number, const bool level) {
  gpio_config_t io_conf_dir = {
      .pin_bit_mask = 1ull << gpio_number,
      .mode = GPIO_MODE_OUTPUT,
      .pull_up_en = GPIO_PULLUP_DISABLE,
      .pull_down_en = GPIO_PULLDOWN_DISABLE,
      .intr_type = GPIO_INTR_DISABLE,
  };
  gpio_config(&io_conf_dir);

  SetLevel(gpio_number, level);
}

/// Init GPIO (Input:Pulldown inner enable)
void InitInput(const gpio_num_t gpio_number) {
  // Input
  gpio_config_t io_input_conf = {
      .pin_bit_mask = 1ull << gpio_number,
      .mode = GPIO_MODE_INPUT,
      .pull_up_en = GPIO_PULLUP_ENABLE,  // IO34-IO39 have no internal
                                         // pull-up/pull-down resistors
      .pull_down_en = GPIO_PULLDOWN_DISABLE,
      .intr_type = GPIO_INTR_ANYEDGE,
  };
  gpio_config(&io_input_conf);
}

/// Set GPIO Level (Output)
void SetLevel(const gpio_num_t gpio_number, const bool level) {
  gpio_set_level(gpio_number, level);
}

/// Get GPIO Level (Input)
bool GetLevel(const gpio_num_t gpio_number) {
  return gpio_get_level(gpio_number) != 0;
}

/// Get ADC Voltage (Input) [mV]
uint32_t GetAdcVoltage(const int32_t adc_channel_no, const int32_t round) {
  adc_oneshot_unit_handle_t adc_handle;
  adc_oneshot_unit_init_cfg_t adcInitConfig = {
      .unit_id = ADC_UNIT_1,
      .clk_src = static_cast<adc_oneshot_clk_src_t>(ADC_DIGI_CLK_SRC_DEFAULT),
      .ulp_mode = ADC_ULP_MODE_DISABLE,
  };
  adc_oneshot_new_unit(&adcInitConfig, &adc_handle);

  adc_oneshot_chan_cfg_t adc_config = {
      .atten = ADC_ATTEN_DB_12,
      .bitwidth = ADC_BITWIDTH_12,
  };
  adc_oneshot_config_channel(
      adc_handle, static_cast<adc_channel_t>(adc_channel_no), &adc_config);

  adc_cali_handle_t adc_cali_handle = nullptr;
  adc_cali_curve_fitting_config_t cali_config = {
      .unit_id = ADC_UNIT_1,
      .chan = static_cast<adc_channel_t>(adc_channel_no),
      .atten = ADC_ATTEN_DB_12,
      .bitwidth = ADC_BITWIDTH_DEFAULT,
  };
  esp_err_t ret =
      adc_cali_create_scheme_curve_fitting(&cali_config, &adc_cali_handle);
  if (ret != ESP_OK) {
    return 0;
  }

  uint32_t sum_voltage = 0;
  for (int32_t i = 0; i < round; ++i) {
    int32_t adc_value = 0;
    adc_oneshot_read(adc_handle, static_cast<adc_channel_t>(adc_channel_no),
                     reinterpret_cast<int*>(&adc_value));
    int32_t adc_voltage = 0;
    adc_cali_raw_to_voltage(adc_cali_handle, adc_value,
                            reinterpret_cast<int*>(&adc_voltage));
    sum_voltage += adc_voltage;
  }

  // Shutdown
  adc_oneshot_del_unit(adc_handle);
  adc_cali_delete_scheme_curve_fitting(adc_cali_handle);

  return sum_voltage / round;
}

}  // namespace gpio
}  // namespace bfox_beacon_system

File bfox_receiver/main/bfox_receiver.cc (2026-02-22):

// ESP32 B-Fox Receiver
// (C)2025 bekki.jp

#include <cstring>
#include <memory>

#include "bfox_receiver.h"
#include "driver/gpio.h"
#include "driver/rtc_io.h"
#include "esp_adc/adc_cali.h"
#include "esp_adc/adc_cali_scheme.h"
#include "esp_sleep.h"
#include "esp_system.h"
#include "esp_timer.h"
#include "gpio_control.h"
#include "i2c_util.h"
#include "logger.h"
#include "nvs_flash.h"
#include "receiver_setting.h"
#include "st7032.h"
#include "util.h"
#include "version.h"
#include "xiao_esp32c6_pin.h"

namespace bfox_receiver_system {

// kA0 Input Enable

// Wakeup GPIO Pin
constexpr gpio_num_t kWakeupGpio = xiao_esp32c6_pin::kD1;

// Major Change GPIO Pin
constexpr gpio_num_t kMajorChangeGpio = xiao_esp32c6_pin::kD10;

// Unused GPIO Pins
const gpio_num_t kUnusedGpioPins[] = {
    xiao_esp32c6_pin::kD2,         xiao_esp32c6_pin::kMtms,
    xiao_esp32c6_pin::kMtdi,       xiao_esp32c6_pin::kMtck,
    xiao_esp32c6_pin::kMtdo,       xiao_esp32c6_pin::kBoot,
    xiao_esp32c6_pin::kLedBuiltin, xiao_esp32c6_pin::kTx,
    xiao_esp32c6_pin::kRx,         xiao_esp32c6_pin::kMosi,
    xiao_esp32c6_pin::kSck,        xiao_esp32c6_pin::kMiso,
    xiao_esp32c6_pin::kSS,
};

constexpr float kBatteryDischargeLimit = 3.2f;
constexpr int kIndicatorRssiNum = 6;
const int kIndicatorRssiTargets[kIndicatorRssiNum] = {INT_MIN, -100, -80,
                                                      -70,     -60,  -50};

static const uint8_t kTargetProximityUuid[16] = {
    0xC6, 0x5B, 0x2C, 0x5D,             // C65B2C5D
    0x9E, 0x53,                         // 9E53
    0x46, 0xEC,                         // 46EC
    0x8B, 0x8E,                         // 8B8E
    0x54, 0xD9, 0xE2, 0xF2, 0x11, 0x88  // 54D9E2F21188
};

constexpr int64_t kSleepTimeoutMs = 30000;  // Enter Deep Sleep after 30s of inactivity
constexpr i2c_port_t kI2cPortNo = I2C_NUM_0;
constexpr int kLcdDisplayLines = 2;

BFoxReceiver::BFoxReceiver()
    : gpio_watcher_(),
      st7032_(),
      beacon_receive_task_(),
      receiver_status_(ReceiverStatus::kSearchMode),
      major_(0),
      sleep_deadline_ms_(0) {}

BFoxReceiver::~BFoxReceiver() = default;

void BFoxReceiver::Start() {
  // Initialize Log
  logger::InitializeLogLevel();

  ESP_LOGI(kTag, "Startup B-Fox Receiver. Version:%s",
           std::string(kGitVersion).c_str());

  // Initialize NVS
  esp_err_t ret = nvs_flash_init();
  if (ret == ESP_ERR_NVS_NO_FREE_PAGES ||
      ret == ESP_ERR_NVS_NEW_VERSION_FOUND) {
    ESP_LOGE(kTag, "NVS Flash Error");
    ESP_ERROR_CHECK(nvs_flash_erase());
    ret = nvs_flash_init();
  }
  ESP_ERROR_CHECK(ret);

  // Get battery voltage
  static const int32_t kVoltageAdcCheckRound = 10;
  const uint32_t adc_voltage =
      gpio::GetAdcVoltage(ADC_CHANNEL_0, kVoltageAdcCheckRound);
  float voltage = 2.0f * adc_voltage / 1000.0f;

  if (voltage <= kBatteryDischargeLimit) {
    ESP_LOGW(kTag, "Battery Voltage is LOW. %4.2fV", voltage);

    st7032_.SetCursor(0, 0);
    st7032_.Printf("LowBattery:%4.2fV", voltage);

    util::SleepMillisecond(3000);
    st7032_.Clear();
    esp_deep_sleep_start();
  }

  // Read Setting
  ReceiverSetting setting;
  setting.Load();
  major_ = setting.GetMajor();

  // Initialize I2C
  i2c_util::InitializeMaster(kI2cPortNo, xiao_esp32c6_pin::kSda,
                             xiao_esp32c6_pin::kScl);

  // ST7032 (LCD Display)
  st7032_.Setup(kI2cPortNo, ST7032::kI2cDefaultAddr, 16, 2);
  st7032_.SetContrast(40);

  // Initial LCD display
  st7032_.SetCursor(0, 0);
  st7032_.Print("B-Fox Receiver  ");
  st7032_.SetCursor(0, 1);
  st7032_.Printf(" Maj:%d Bat:%4.2fV", major_, voltage);

  // Use Ext Antenna
  gpio::InitOutput(xiao_esp32c6_pin::kWifiEnable,
                   false);  // Activate RF switch control (kWifiEnable = False)
  util::SleepMillisecond(100);
  gpio::InitOutput(xiao_esp32c6_pin::kWifiAntConfig,
                   true);  // Use external antenna (KWifiAntConfig = True)

  // Set unused GPIOs to input with pull-up for stability
  for (const auto& gpio_num : kUnusedGpioPins) {
    gpio_set_direction(gpio_num, GPIO_MODE_INPUT);
    gpio_set_pull_mode(gpio_num, GPIO_PULLDOWN_ONLY);
  }

  // Configure RTC pullup for kWakeupGpio first, then AddMonitor() (which calls
  // gpio_config() internally) will switch the pin back to Digital GPIO control.
  // On Deep Sleep, esp_sleep_enable_ext1_wakeup() restores RTC control automatically.
  rtc_gpio_init(kWakeupGpio);
  rtc_gpio_pullup_en(kWakeupGpio);
  rtc_gpio_pulldown_dis(kWakeupGpio);

  // Set Button Event
  gpio_watcher_.AddMonitor(
      GpioInputWatchTask::GpioInfo(
          kWakeupGpio, std::bind(&BFoxReceiver::OnActivityButton, this),
          nullptr),
      GpioInputWatchTask::GpioPullUpDown::kPullUpResistorEnable);
  gpio_watcher_.AddMonitor(
      GpioInputWatchTask::GpioInfo(
          kMajorChangeGpio, std::bind(&BFoxReceiver::OnSetMajorButton, this),
          std::bind(&BFoxReceiver::OnSetMajorLongButton, this)),
      GpioInputWatchTask::GpioPullUpDown::kPullUpResistorEnable);
  gpio_watcher_.Start();

  esp_sleep_enable_ext1_wakeup((1ULL << kWakeupGpio), ESP_EXT1_WAKEUP_ANY_LOW);

  // Ble Receive Task
  beacon_receive_task_ =
      std::make_unique<BeaconReceiveTask>(kTargetProximityUuid, major_);
  if (!beacon_receive_task_) {
    return;
  }
  beacon_receive_task_->Start();

  ESP_LOGI(kTag, "Activation Complete B-Fox Receiver System.");

  // Set initial sleep deadline
  sleep_deadline_ms_ = esp_timer_get_time() / 1000 + kSleepTimeoutMs;

  util::SleepMillisecond(2000);  // Initial wait time

  while (true) {
    if (receiver_status_ == ReceiverStatus::kSearchMode) {
      BeaconSearchMode();
    } else if (receiver_status_ == ReceiverStatus::kSettingMode) {
      SettingMode();
    } else if (receiver_status_ == ReceiverStatus::kSettingFinishMode) {
      SettingFinishMode();
    }
  }
}
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

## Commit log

2025-09-30 Added beacon and receiver code
    [partitions.csv]
2025-09-30 Rename project from BRDF to BleRDF
    Rename all project directories, files, and references from brdf_ to blerdf_ to better reflect the Bluetooth Low Energy RDF functionality. Update documentation to match the new naming convention.
    [partitions.csv]
2025-10-04 Add PCB data
    [BleRDF_beacon.kicad_pcb, BleRDF_beacon.kicad_sch, BleRDF_receiver.kicad_pcb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]
2025-10-10 Update PCB wiring and add 3D case models
    [BleRDF_Beacon_Case.FCStd, BleRDF_Receiver_Case.FCStd, BleRDF_beacon.kicad_pcb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]
2025-10-10 Update monitoring LED pin from D9 to D7 in beacon Update major change button GPIO from D7 to D10 in receiver Change pull resistor mode from pull-up to pull-down for lower power consumption Update .gi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
2025-10-11 Update 3D cases and pcb,hardware documentation
    [BleRDF_Beacon_Case-Body.step, BleRDF_Beacon_Case-Lid.step, BleRDF_Beacon_Case-PCBCover.step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]
2025-10-11 Fix Receiver PCB Cover
    [BleRDF_Beacon_Case.FCStd, BleRDF_Receiver_Case-PCBCover.step, BleRDF_Receiver_Case.FCStd]
2025-10-20 Fix interference of screw holes for cover mounting
    [BleRDF_Beacon_Case-Body.step, BleRDF_Beacon_Case.FCStd, BleRDF_Receiver_Case-Body.step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]
2025-10-22 Fix LED Connector Directon BleRDF_Beacon PCB
    [BleRDF_beacon.kicad_pcb, BleRDF_beacon.kicad_sch]
2025-10-22 Update PCB Gerber data
2025-10-31 Fix PCBCover hole
    [BleRDF_Beacon_Case-Body.step, BleRDF_Beacon_Case-PCBCover.step, BleRDF_Beacon_Case.FCStd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]
2025-11-08 change project name. BleRDF -> B-Fox
    [BleRDF_Beacon_Case-Body.step, BleRDF_Beacon_Case-Lid.step, BleRDF_Beacon_Case-PCBCover.step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]
2025-11-13 Convert Case StepFile
    [bfox_beacon_case-Body.step, bfox_beacon_case-Lid.step, bfox_beacon_case-PCBCover.step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]
2026-02-19 Fix Receiver Case CAD Data and add icon.svg
    [bfox_Receiver_Case.FCStd, bfox_receiver_case-LCDFix.step]
2026-02-21 extend sleep timer on activity
2026-02-21 Fix use continuous BLE scan to reduce NO SIGNAL occurrences
    [bfox_receiver.cc]
2026-02-21 add battery level bar graph and percentage display to web client
2026-02-21 Fix battery display: show voltage only, ensure bar renders
2026-02-22 Switch to NimBLE stack for iBeacon and GATT services
2026-02-22 Fix advertising interval application and change default to 500ms
    [bfox_beacon.cc]
2026-03-10 Add fine-grained TX power levels from +9dBm to -15dBm for beacon output control
2026-05-10 iOSアプリに音声案内機能を追加
2026-05-11 アクセシビリティ機能として触感フィードバック機能を追加
